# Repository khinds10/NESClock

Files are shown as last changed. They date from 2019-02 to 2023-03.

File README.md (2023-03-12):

# 8 Bit Sprite Clock
Game Room Nintendo Time w/ Friendly Sprites to greet you

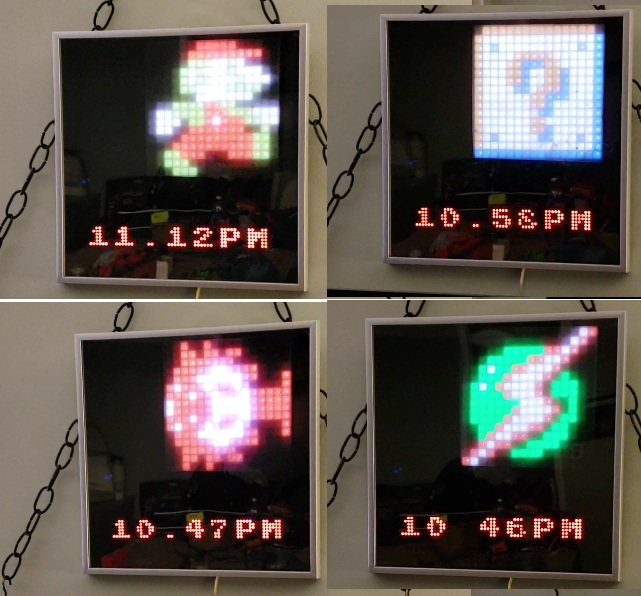
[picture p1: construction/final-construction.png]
Final Construction


Preview

#### Flashing RaspberriPi Hard Disk / Install Required Software (Using Ubuntu Linux)

Download "RASPBIAN JESSIE LITE"
https://www.raspberrypi.org/downloads/raspbian/

**Create your new hard disk for DashboardPI**
>Insert the microSD to your computer via USB adapter and create the disk image using the `dd` command
>
> Locate your inserted microSD card via the `df -h` command, unmount it and create the disk image with the disk copy `dd` command
>
> $ `df -h`
> */dev/sdb1       7.4G   32K  7.4G   1% /media/XXX/1234-5678*
>
> $ `umount /dev/sdb1`
>
> **Caution: be sure the command is completely accurate, you can damage other disks with this command**
>
> *if=location of RASPBIAN JESSIE LITE image file*
> *of=location of your microSD card*
>
> $ `sudo dd bs=4M if=/path/to/raspbian-jessie-lite.img of=/dev/sdb`
> *(note: in this case, it's /dev/sdb, /dev/sdb1 was an existing factory partition on the microSD)*

**Setting up your RaspberriPi**

*Insert your new microSD card to the raspberrypi and power it on with a monitor connected to the HDMI port*

Login
> user: **pi**
> pass: **raspberry**

Change your account password for security
>`sudo passwd pi`

Enable RaspberriPi Advanced Options
>`sudo raspi-config`

Choose:
`1 Expand File System`

`9 Advanced Options`
>`A2 Hostname`
>*change it to "SpriteClock"*
>
>`A4 SSH`
>*Enable SSH Server*
>
>`A7 I2C`
>*Enable i2c interface*

**Enable the English/US Keyboard**

>`sudo nano /etc/default/keyboard`

> Change the following line:
>`XKBLAYOUT="us"`

**Reboot PI for Keyboard layout changes / file system resizing to take effect**
>$ `sudo shutdown -r now`

**Auto-Connect to your WiFi**

>`sudo nano /etc/wpa_supplicant/wpa_supplicant.conf`

Add the following lines to have your raspberrypi automatically connect to your home WiFi
*(if your wireless network is named "linksys" for example, in the following example)*

	network={
	   ssid="linksys"
	   psk="WIRELESS PASSWORD HERE"
	}

**Reboot PI to connect to WiFi network**

>$ `sudo shutdown -r now`
>
>Now that your PI is finally on the local network, you can login remotely to it via SSH.
>But first you need to get the IP address it currently has.
>
>$ `ifconfig`
>*Look for "inet addr: 192.168.XXX.XXX" in the following command's output for your PI's IP Address*

**Go to another machine and login to your raspberrypi via ssh**

> $ `ssh pi@192.168.XXX.XXX`

**Start Installing required packages**

>$ `sudo apt-get update`
>
>$ `sudo apt-get upgrade`
>
>$ `sudo apt-get install vim git python-smbus i2c-tools python-imaging python-smbus build-essential python-dev rpi.gpio python3 python3-pip python-numpy`

**Update local timezone settings**

>$ `sudo dpkg-reconfigure tzdata`

`select your timezone using the interface`

**Setup the simple directory `l` command [optional]**

>`vi ~/.bashrc`
>
>*add the following line:*
>
>`alias l='ls -lh'`
>
>`source ~/.bashrc`

**Fix VIM default syntax highlighting [optional]**

>`sudo vi  /etc/vim/vimrc`
>
>uncomment the following line:
>
>_syntax on_

**Install i2c Backpack Python Drivers**

>$ `cd ~`
>
>$ `pip3 install adafruit-circuitpython-ht16k33`

**Install i2c Python Drivers**

Install the NeoPixel Driver as follows 

>`sudo apt-get install build-essential python-dev git scons swig`
>
>`sudo pip3 install --upgrade setuptools`
>
>`sudo pip3 install rpi_ws281x`
>
>`cd rpi_ws281x`
>
>`scons`
>
>`cd python`
>
>`sudo python setup.py install`
>
>`cd examples/`
>
>`sudo python strandtest.py`

**Clone the repository in your home directory for the clock to work**

> `cd ~`
>
> `git clone https://github.com/khinds10/NESClock.git`

# Supplies Needed

**Pi Zero W/1.3/1.2**

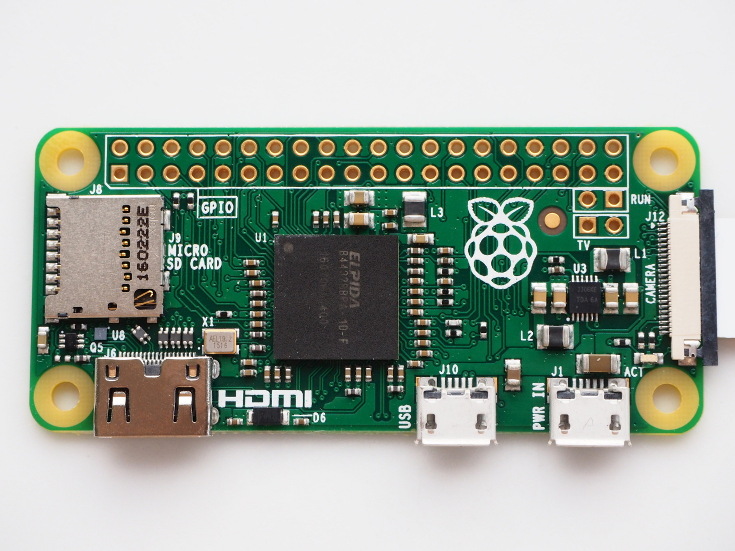
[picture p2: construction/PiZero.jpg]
Pi Zero


**Wifi USB (if Pi Zero 1.3/1.2)**

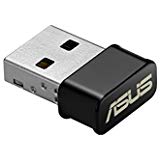
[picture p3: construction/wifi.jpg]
WIFI USB


**Keyestudio I2C 8x8 LED Matrix HT16K33 (x7)**

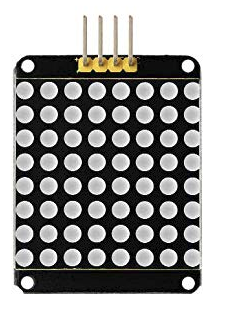
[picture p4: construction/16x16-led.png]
LED 16x16 LED 16x16 Matrix


**16x16 RGB LED Flexible WS2812B Matrix**

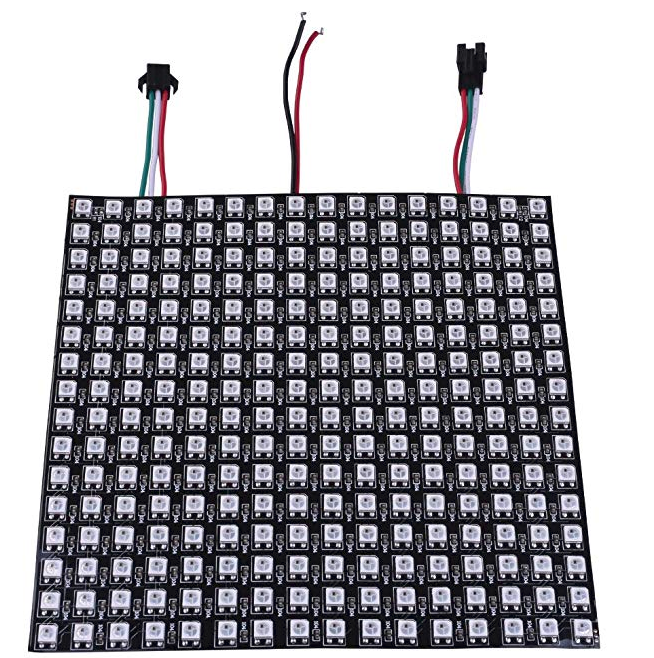
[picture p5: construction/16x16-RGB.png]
WS2812B Matrix


**Frosted Paint**

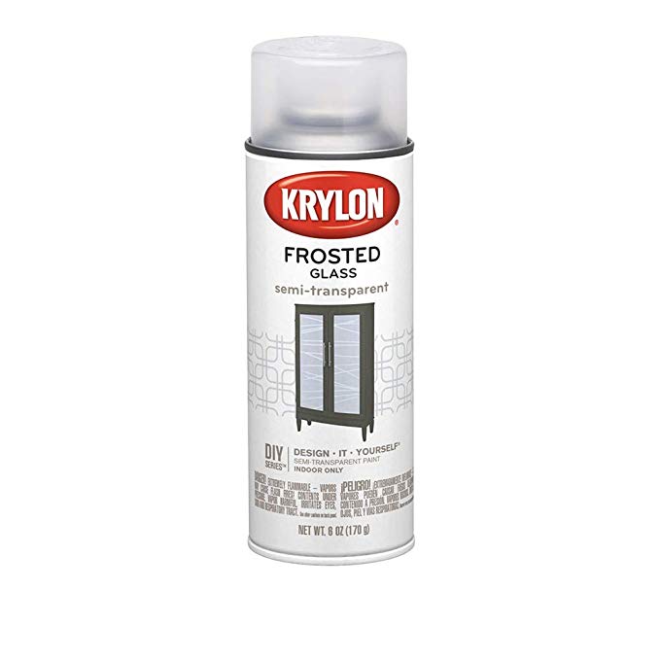
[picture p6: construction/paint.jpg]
Frosted Paint


**12x12 Picture Frame**

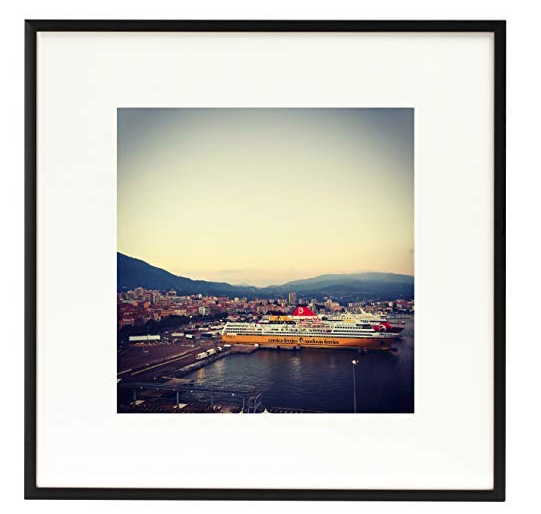
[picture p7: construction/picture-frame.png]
Picture Frame


**Cuttable thin plexi-glass sheet**

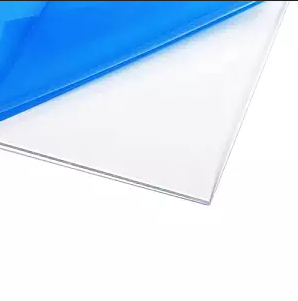
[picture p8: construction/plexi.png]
Thin Plexi Glass Sheet


**12x12" 2 way mirror plexi-glass sheet**

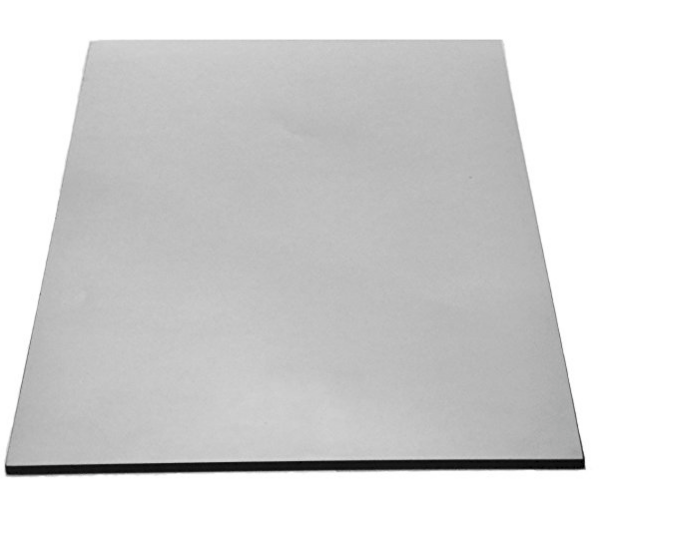
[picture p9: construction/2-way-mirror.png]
2 Way Mirror


**12x12" tinted plexi-glass sheet**

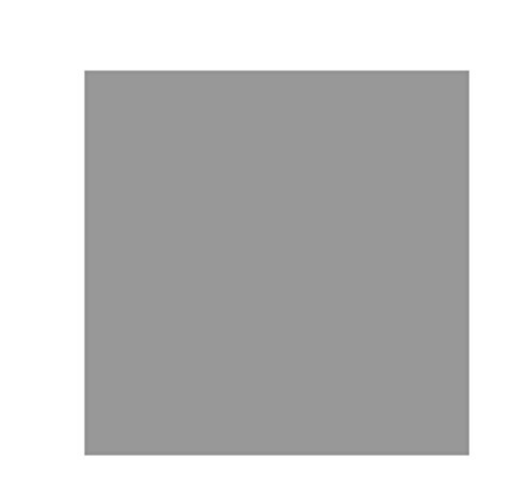
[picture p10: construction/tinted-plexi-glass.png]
Tinted Plexi-Glass


# Building the Sprite Clock

**1) Prepare the HT16K33 matrix units** 

Solder the pins on the back to assign them each a unique i2c address.  There are 3 jumpers to solder or not solder in 8 combinations.  I've soldered all combinations to assign each unit a different address to be accessed by the python code to show the clock time.

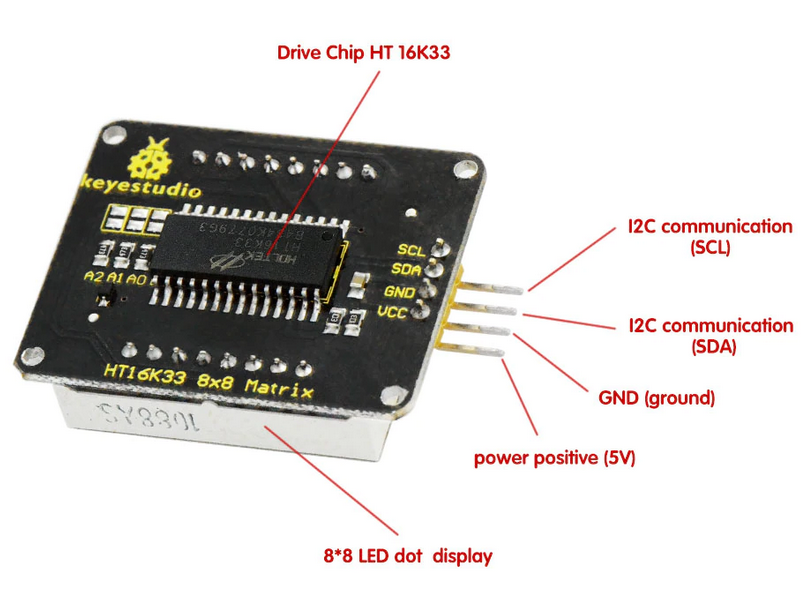
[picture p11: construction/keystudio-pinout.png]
Keystudio Pinout


**2) Print the Project Enclosure**

In the 3D print folder find the "defuser-grid-final.stl" print model to be a working pixel defuser to focus the light from each LED to a square shape to enhance the output of the sprites on the clock.

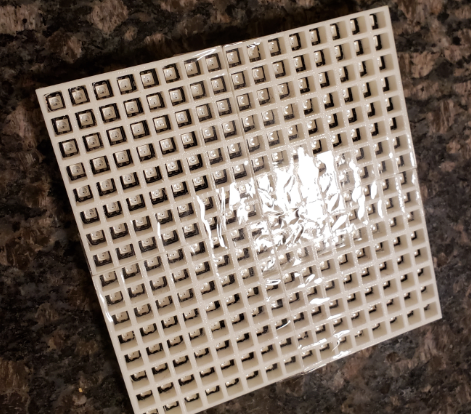
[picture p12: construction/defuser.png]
Defuser


**3) Tape the printed pixel defuser to the LED matrix, spray frosted white paint and cut a piece of thin plexi-glass to then tape over the top of the defuser.**  

This will continue to scatter the light even more to improve the sprite clarity.

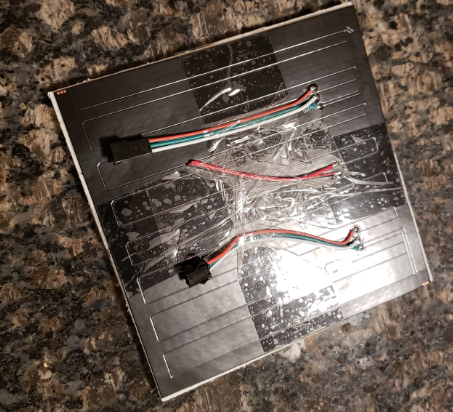
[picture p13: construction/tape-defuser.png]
Tape Defuser


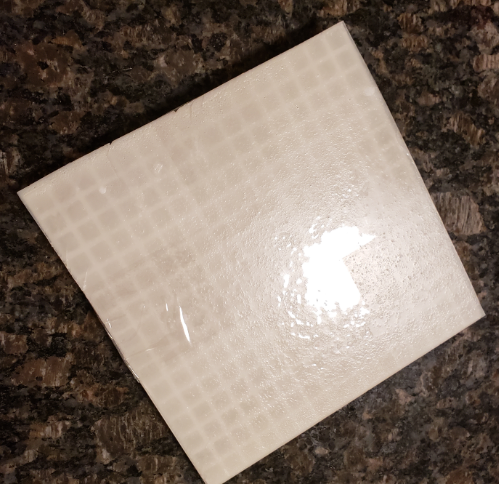
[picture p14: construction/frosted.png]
Frosted Defuser


**4) Begin wiring the devices**

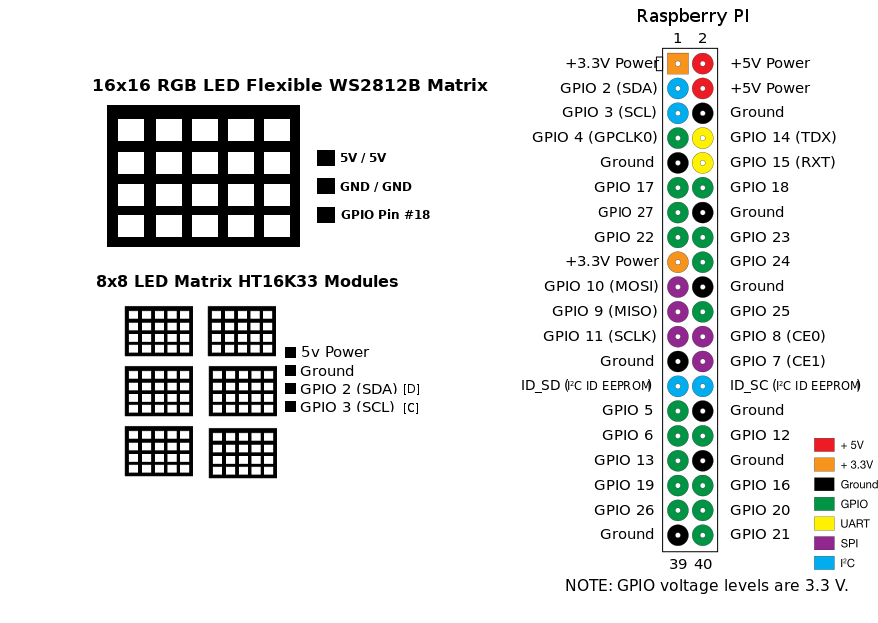
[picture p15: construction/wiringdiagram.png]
Wiring Diagram


**HT16K33 Matrix Units**

> GND -> GND
>
> DATA -> SDA
>
> CLK -> SCL
>
> VCC -> 5V

**RGB 16x16 Unit**

> GND -> GND
>
> DATA -> GPIO 18
>
> VCC -> 5V

**5) In place of the normal picture frame glass, replace it with the 2 way mirror (12x12" sheet) and gray tinted plastic glass (12x12" sheet).**  

This will conceal the components inside the frame, so you can see only the pixel light output.

**6) Tape together the HT16K33 units in a solid row**

Make sure each unit is addressed from \0x70 to \0x76 in a row for the code to work (you can adjust the code if they're out of order later)

**7) Place the components level side the frame with the mirror and tinted glass installed.**

Now you can place the back of the frame on to hold the components in place.  This will be the hardest part, I was lucky to have a frame with a flexible enough back.  I got everything level and it looked great.

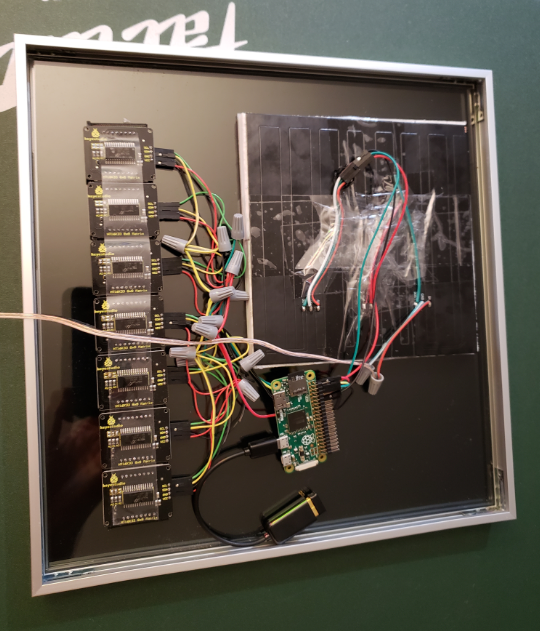
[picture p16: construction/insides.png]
Assemble Insides


### Set pi user crontab 

Enter the following line for a minute by minute crontab

`$ crontab -e`

`@reboot nohup python /home/pi/NESClock/MatrixClock.py > /dev/null 2>&1`

### Set root user crontab (RGB Sprite Panel library requires root access)

Set "on reboot" to run the candle python script forever

`$ sudo su`

`$ crontab -e`

`@reboot nohup python /home/pi/NESClock/SpritePanel.py > /dev/null 2>&1`

# Finished!

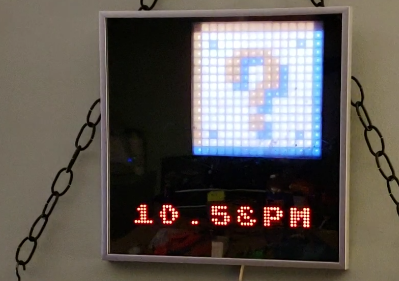
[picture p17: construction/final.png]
Final


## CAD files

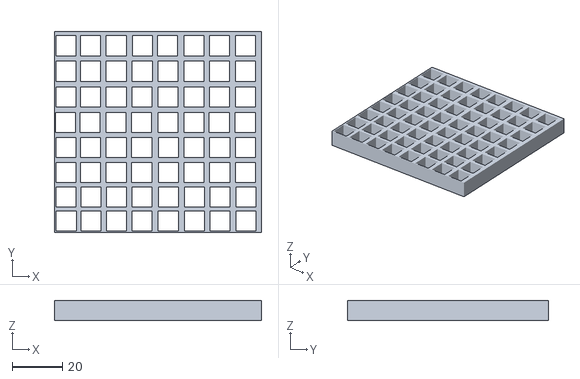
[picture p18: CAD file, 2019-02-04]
3DPrint/defuser-grid-final.stl
82.5 x 80.0 x 8.00

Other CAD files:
3DPrint/defuser-grid-final.blend

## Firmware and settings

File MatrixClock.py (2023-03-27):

#!/usr/bin/python3
# Kevin Hinds http://www.kevinhinds.com
# License: GPL 2.0
import time, board
from PIL import Image, ImageDraw, ImageFont
from adafruit_ht16k33.matrix import Matrix8x8

# all the displays by I2C address
i2c = board.I2C()
displayBrightness = 0.5
displays = [Matrix8x8(i2c,address=0x70), Matrix8x8(i2c,address=0x71), Matrix8x8(i2c,address=0x72), Matrix8x8(i2c,address=0x73), Matrix8x8(i2c,address=0x74), Matrix8x8(i2c,address=0x75), Matrix8x8(i2c,address=0x76)]

def clearDisplays():
    """clear all the displays in the clock"""
    global displayBrightness
    for display in displays:
        display.brightness = displayBrightness
        display.fill(0)

def writeCharacter(displayNumber, textValue):
    """for given display number, write the text value"""
    global displays
    image = Image.new('1', (8, 8))
    draw = ImageDraw.Draw(image)
    fnt = ImageFont.truetype('/home/khinds/NESClock/LED.ttf', 10)
    draw.text((0,0), textValue, font=fnt, fill=255)
    image  = image.transpose(Image.ROTATE_270)
    displays[displayNumber].image(image)

def writeTime(value, isChanged):
    """for a complete time string, write it to the clock"""

    # if the time has changed, then animate
    if (isChanged):        
        for display in displays:
            display.shift_right(True)
            time.sleep(0.01)
            display.shift_up(True)
            time.sleep(0.01)
            display.shift_left(True)
            time.sleep(0.01)
            display.shift_down(True)
            time.sleep(0.01)    

    count = 6
    for c in value:
        writeCharacter(count, c)
        count = count - 1


# clear displays and start the time, with a blinking colon
clearDisplays()
showColon = True
currentShownTime = ""
while True:
    currentTime = time.strftime("%I:%M%p")
    if showColon == True:
        now = time.strftime("%I:%M%p")
    if showColon == False:
        now = time.strftime("%I %M%p")
    writeTime(now, (currentShownTime != currentTime))
    currentShownTime = currentTime
    showColon = not showColon
    time.sleep(1)

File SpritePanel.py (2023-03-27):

#!/usr/bin/python
# Kevin Hinds http://www.kevinhinds.com
# License: GPL 2.0
from __future__ import division
import time, sched, json, string, cgi, subprocess, json, datetime, glob, numpy, random
from rpi_ws281x import PixelStrip, Color
from PIL import Image

# LED strip configuration:
LED_COUNT      = 256     # Number of LED pixels.
LED_PIN        = 18      # GPIO pin connected to the pixels (18 uses PWM!).
LED_FREQ_HZ    = 800000  # LED signal frequency in hertz (usually 800khz)
LED_DMA        = 10      # DMA channel to use for generating signal (try 10)
LED_BRIGHTNESS = 10      # Set to 0 for darkest and 255 for brightest
LED_INVERT     = False   # True to invert the signal (when using NPN transistor level shift)
LED_CHANNEL    = 0       # set to '1' for GPIOs 13, 19, 41, 45 or 53

############################################
######## YOU HAVE TO RUN AS ROOT!
############################################

# Create NeoPixel object with appropriate configuration.
strip = PixelStrip(LED_COUNT, LED_PIN, LED_FREQ_HZ, LED_DMA, LED_INVERT, LED_BRIGHTNESS, LED_CHANNEL)

# Intialize the library (must be called once before other functions).
strip.begin()

def prepareSpriteForMatrix(imagePixels):
    """ create final LED pixels list for display, the pixel indexes zig-zag back and forth on the LED matrix """
    finalLEDPixels = []
    rowIndex = 0

    # every other row is reversed because the pixel positions are zig-zag back and forth as you cound
    for row in imagePixels:
        if rowIndex % 2 == 0:
            row = numpy.flipud(row)
        rowIndex = rowIndex + 1
        for pixel in row:
            finalLEDPixels.append(pixel)
    return finalLEDPixels

scheduler = sched.scheduler(time.time, time.sleep)
def animateRandomSprite(sc):
    """ get a random sprite sequence to animate on the panel, updating each minute """
    try:   
        files = glob.glob("/home/khinds/NESClock/sprites/**/")
        selectedSprite = random.choice(files)
        selectedSpriteFrames = glob.glob(selectedSprite + "/*.bmp")
        selectedSpriteFrames.sort()

        # create an array of LED matrix friendly pixels
        spriteFrameRawData = []
        for spriteFrame in selectedSpriteFrames:
            im = Image.open(spriteFrame, 'r')
            imagePixels = numpy.split(numpy.asarray(list(im.getdata())), 16)
            spriteFrameRawData.append(prepareSpriteForMatrix(imagePixels))
        
        # render all pixel values as colors on the matrix frame by frame, dividing equally inside of 1 second of animation
        animationCount = 0
        while animationCount < 12:
            for spriteFrame in spriteFrameRawData:
                for i in range(0, strip.numPixels(), 1):
                    strip.setPixelColor(i, Color(int(spriteFrame[i][0]), int(spriteFrame[i][1]), int(spriteFrame[i][2])))
                    
                    
                    #strip.setPixelColor(i, Color(int(spriteFrame[i][2]), int(spriteFrame[i][1]), int(spriteFrame[i][0])))
                    
                strip.show()
                time.sleep(1/len(selectedSpriteFrames))
            animationCount = animationCount + 1

        scheduler.enter(1, 1, animateRandomSprite, (sc,))
    except:
        animateRandomSprite(0)
    
# start animating!
animateRandomSprite(0)
scheduler.run()
